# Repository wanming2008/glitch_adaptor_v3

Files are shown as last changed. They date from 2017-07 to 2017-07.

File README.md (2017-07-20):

# glitch_adaptor_v3

Voltage glitching driver board using LM5134 and IRF7607.

This is designed for use with the ChipWhisperer-Lite. For best performance, physically remove or disconnect the built-in glitching FETs on the CW-Lite board and connect the gate drive signal to this glitching board via coax. The connection from glitch board to target Vcore signal should be very short, I used about a centimeter of twisted heavy-gauge magnet wire. The FET drivers run from 12.5 volts to get the fastest slew rates we can. This circuit switches in a capacitor bank to stabilize Vcore when not glitching, intended for use with chips that have a low voltage core with a built-in regulator.

Board layout for KiCad, thrown together for quick assembly using the parts I had on hand. You may want to substitute your favorite voltage regulators if you like.

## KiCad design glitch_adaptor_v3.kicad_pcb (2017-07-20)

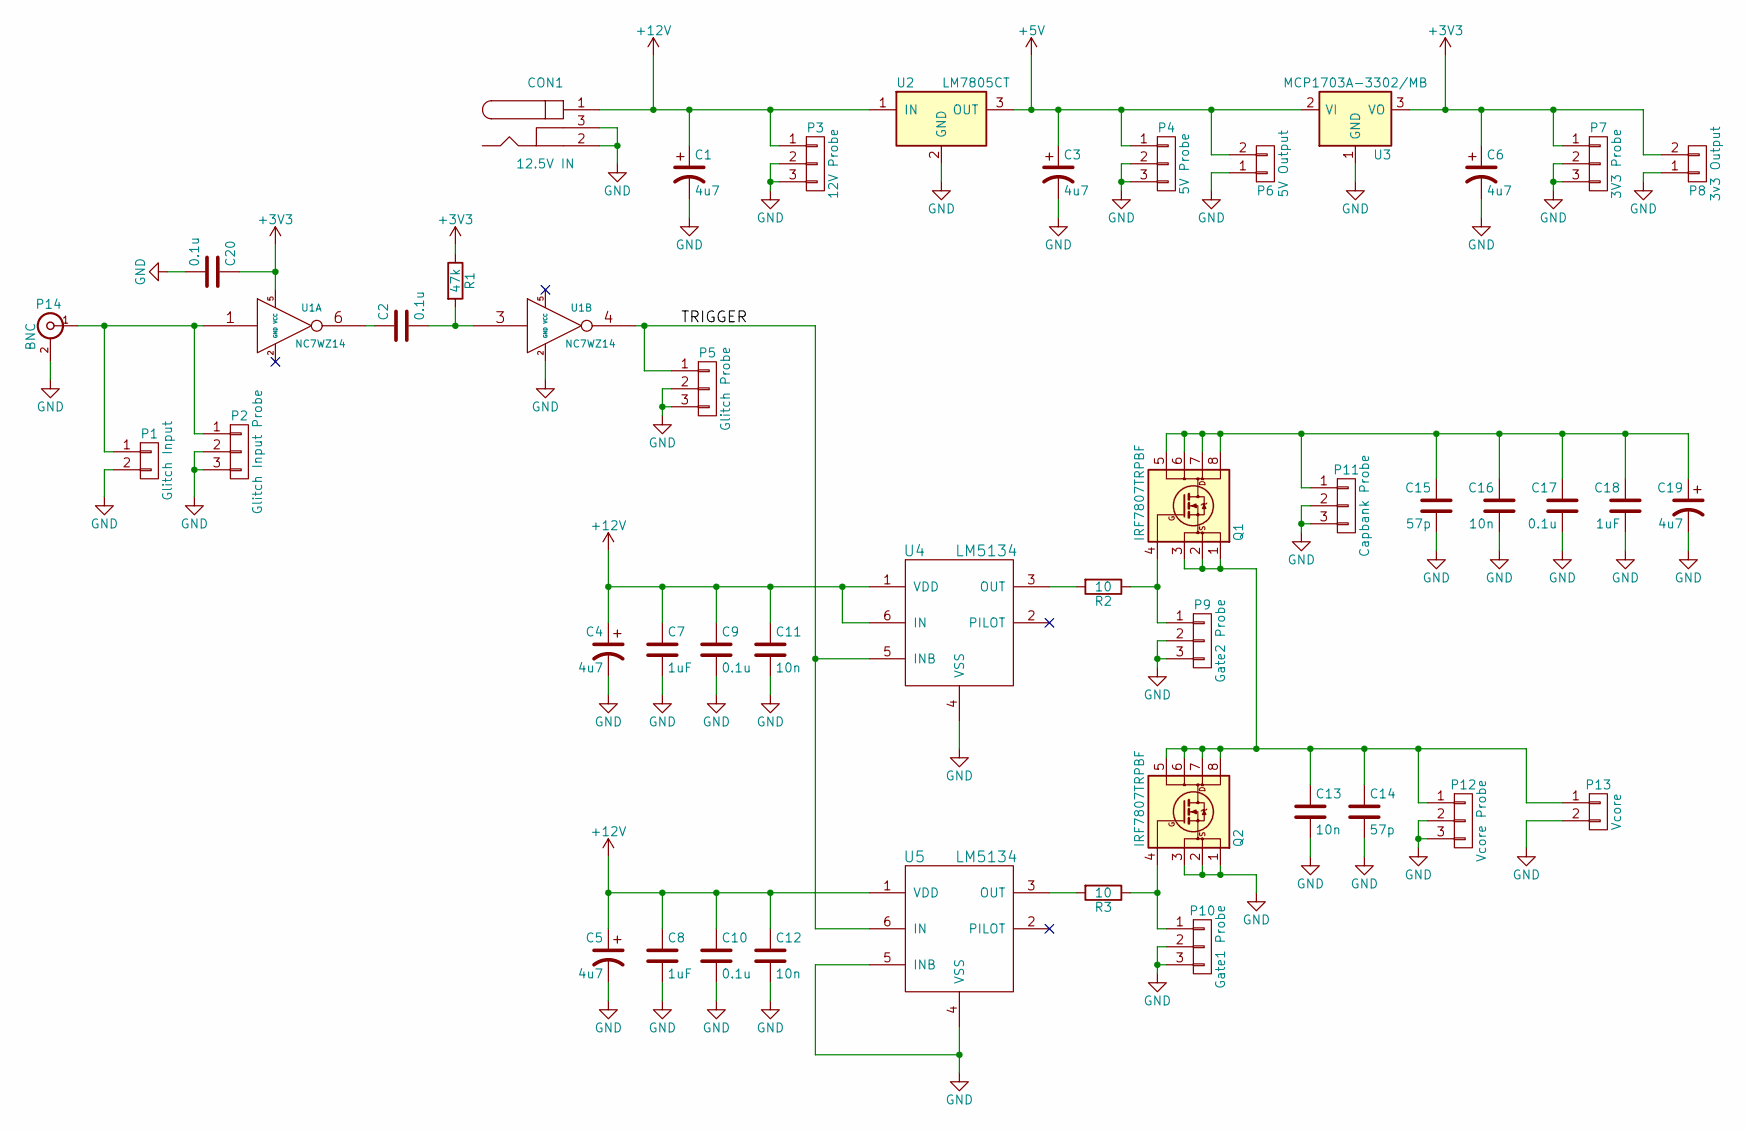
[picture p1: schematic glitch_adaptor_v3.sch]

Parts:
C1, C3, C4, C5, C6, C19: 4u7; C_1206_HandSoldering
C2, C9, C10, C17, C20: 0.1u; C_0805_HandSoldering
C7, C8, C18: 1uF; C_0805_HandSoldering
C11, C12, C13, C16: 10n; C_0805_HandSoldering
C14, C15: 57p; C_0805_HandSoldering
CON1: 12.5V IN; BARREL_JACK
P1: Glitch Input; Pin_Header_Straight_1x02
P2: Glitch Input Probe; ScopeProbe3pin
P3: 12V Probe; ScopeProbe3pin
P4: 5V Probe; ScopeProbe3pin
P5: Glitch Probe; ScopeProbe3pin
P6: 5V Output; Pin_Header_Straight_1x02
P7: 3V3 Probe; ScopeProbe3pin
P8: 3v3 Output; Pin_Header_Straight_1x02
P9: Gate2 Probe; ScopeProbe3pin
P10: Gate1 Probe; ScopeProbe3pin
P11: Capbank Probe; ScopeProbe3pin
P12: Vcore Probe; ScopeProbe3pin
P13: Vcore; Pin_Header_Straight_1x02
P14: BNC; SMB_Straight
Q1, Q2: IRF7807TRPBF; SOIC-8_3.9x4.9mm_Pitch1.27mm
R1: 47k; R_0805_HandSoldering
R2, R3: 10; R_0805_HandSoldering
U1: NC7WZ14; SC-70-6_Handsoldering
U2: LM7805CT; TO-220_Neutral123_Horizontal_LargePads
U3: MCP1703A-3302/MB; TO-92_Rugged
U4, U5: LM5134; SOT-23-6_Handsoldering

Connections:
+3V3: C6.1, C20.1, P7.1, P8.2, R1.1, U1.5 (VCC), U3.3 (VO)
+5V: C3.1, P4.1, P6.2, U2.3 (OUT), U3.2 (VI)
+12V: C1.1, C4.1, C5.1, C7.1, C8.1, C9.1, C10.1, C11.1, C12.1, CON1.1, P3.1, U2.1 (IN), U4.1 (VDD), U4.6 (IN), U5.1 (VDD)
/TRIGGER: P5.1, U1.4, U4.5 (INB), U5.6 (IN)
GND: C1.2, C3.2, C4.2, C5.2, C6.2, C7.2, C8.2, C9.2, C10.2, C11.2, C12.2, C13.2, C14.2, C15.2, C16.2, C17.2, C18.2, C19.2, C20.2, CON1.2, CON1.3, P1.2, P2.2, P2.3, P3.2, P3.3, P4.2, P4.3, P5.2, P5.3, P6.1, P7.2, P7.3, P8.1, P9.2, P9.3, P10.2, P10.3, P11.2, P11.3, P12.2, P12.3, P13.2, P14.2 (Ext), Q2.1 (S), Q2.2 (S), Q2.3 (S), U1.2 (GND), U2.2 (GND), U3.1 (GND), U4.4 (VSS), U5.4 (VSS), U5.5 (INB)
unnamed: C2.1, U1.6
unnamed: C2.2, R1.2, U1.3
unnamed: C13.1, C14.1, P12.1, P13.1, Q1.1 (S), Q1.2 (S), Q1.3 (S), Q2.5 (D), Q2.6 (D), Q2.7 (D), Q2.8 (D)
unnamed: C15.1, C16.1, C17.1, C18.1, C19.1, P11.1, Q1.5 (D), Q1.6 (D), Q1.7 (D), Q1.8 (D)
unnamed: P1.1, P2.1, P14.1 (In), U1.1
unnamed: P9.1, Q1.4 (G), R2.1
unnamed: P10.1, Q2.4 (G), R3.1
unnamed: R2.2, U4.3 (OUT)
unnamed: R3.2, U5.3 (OUT)

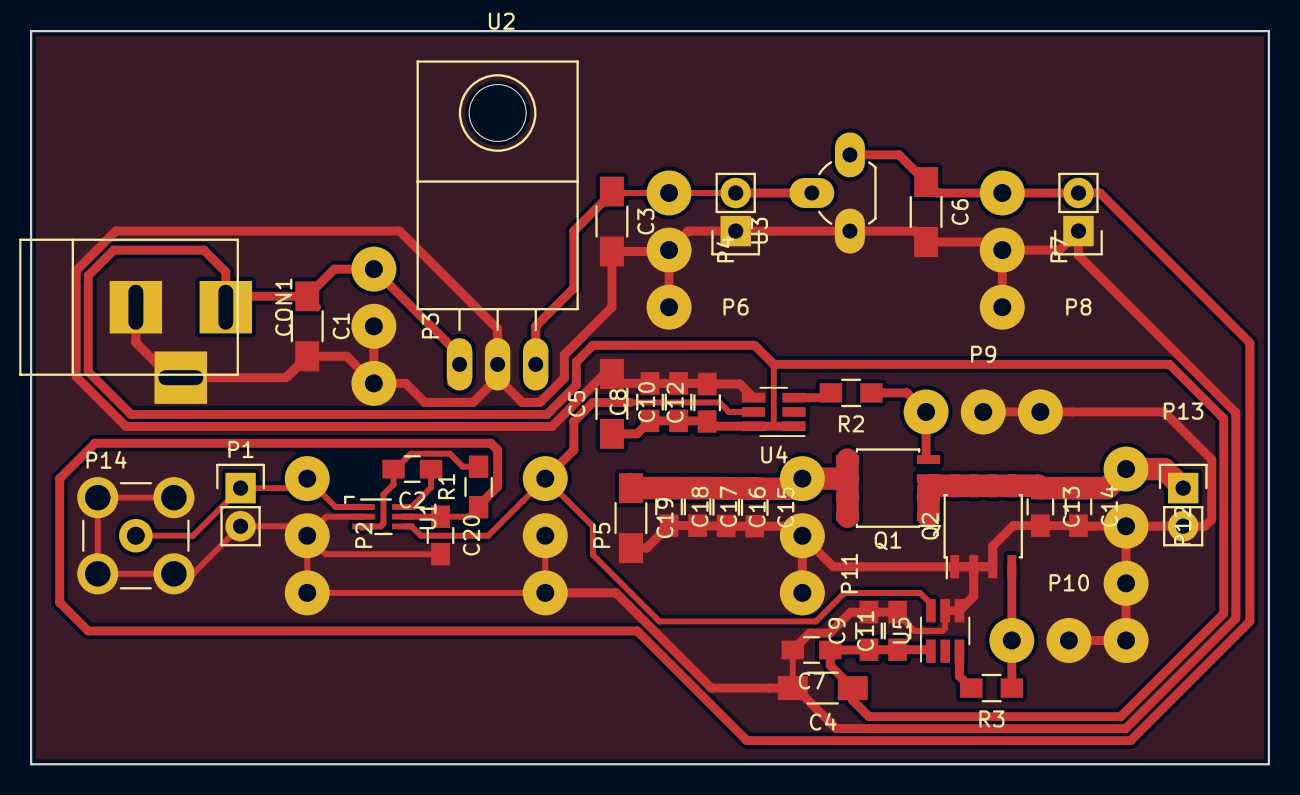
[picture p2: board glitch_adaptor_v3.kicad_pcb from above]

Board: 2 copper layers, 82.6 x 48.9 mm, 45 parts (0 on the bottom side), 14 nets.
